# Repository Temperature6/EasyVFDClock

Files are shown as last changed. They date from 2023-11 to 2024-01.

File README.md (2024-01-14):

# STM32 - VFD Clock

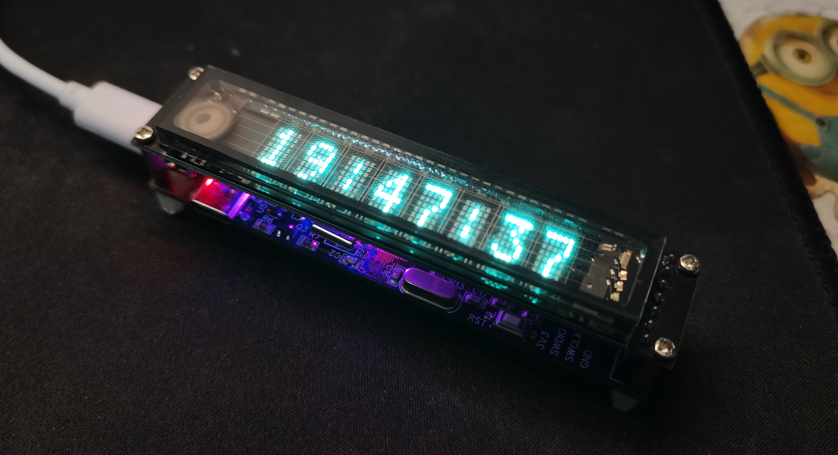
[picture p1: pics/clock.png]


### 简介

基于STM32F103C8T6的时钟，屏幕是VFD屏幕（Vaccum Fluorescent Display，真空荧光显示屏）

**功能**：时间显示，日期显示，开机显示字符串，可控的三个彩色LED（V1版本目前除了可控的常亮常灭没有其他功能），按键校时，上位机校时，设置亮屏时间，支持一键烧录

**上位机功能**：校时，设置日期显示格式，设置开机字符串，屏幕保护设置，LED设置，亮度设置（Python版的上位机提供了命令行批量操作，Qt版没有）

### 说明

#### **1.时钟电路**

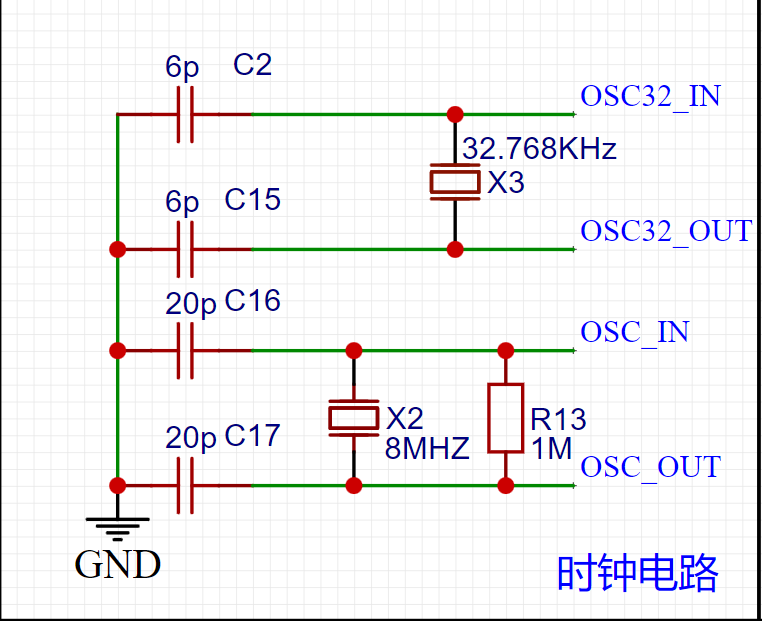
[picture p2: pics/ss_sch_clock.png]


32.768KHz晶振的起振电容（C2，C15）最好选择6pF，或者不贴

我选的低速晶振是是±5ppm的高精度晶振，实测在24℃的室内大概每天快4秒，如果能买到更高精度的晶振也可以用

#### **2.串口电路**

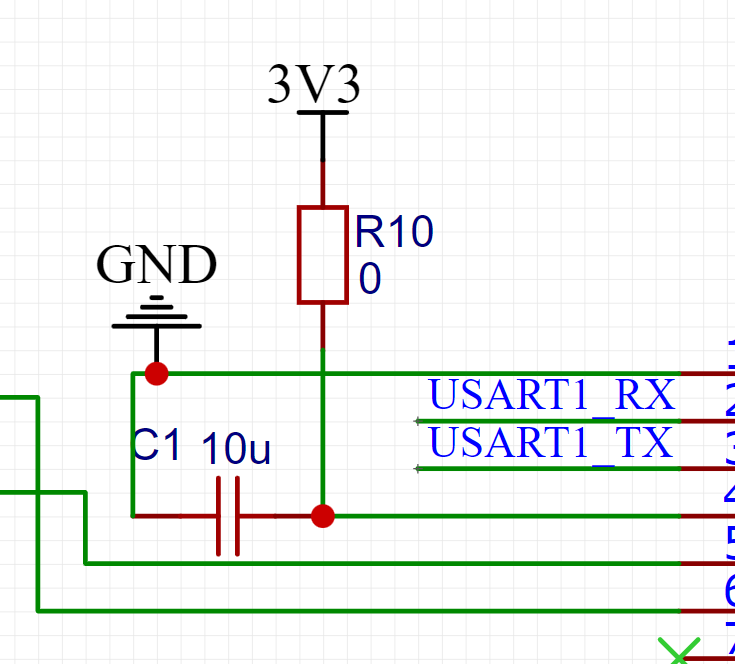
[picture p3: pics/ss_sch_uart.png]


C1是ch340c的去耦电容，贴0.1uF或者10uF，R10可以不贴

#### 3.测试点

背后有多个测试点

**B1_0：** STM32单片机BOOT1拉低（**需要连接**）

**B0_0：** STM32单片机BOOT0拉低（不需要连接，串口烧录电路自带下拉，但是连接也没什么影响，可以删去）

**B1_1：** STM32单片机BOOT1拉高（不需要连接，可以删去）

**B0_1：** STM32单片机BOOT0拉高（不需要连接，可以删去）

**WP_TO_GND：** EEPROM的WP引脚拉低，拉高之后AT24C02进入写保护模式，这里的设计实际上有问题，测试点另一边应该连接VCC，（写保护模式启用后，数据只能读出不能写入，一般不需要连接，可以删去）

**EN_A1：** VFD屏幕的EN引脚是否连接到单片机的PA1引脚（**需要连接**）

**EN_5V：** VFD屏幕的EN引脚是否连接到5V引脚，这样屏幕不受单片机控制了（不需要连接，可以删去）

大部分不需要连接的测试点都可以删去，设计的时候是为了防止再版多弄了几个

#### **4.安装**

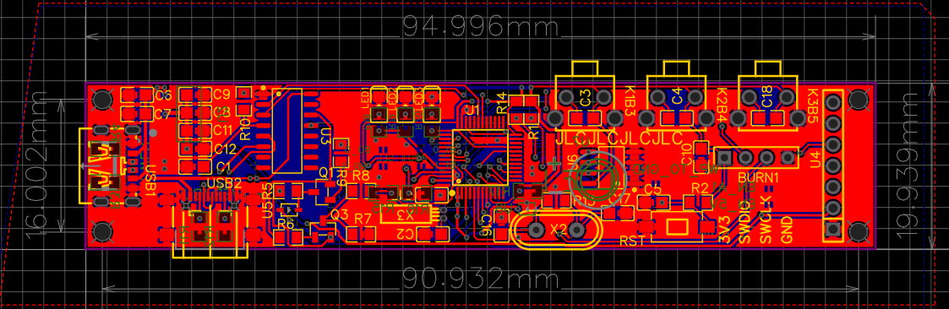
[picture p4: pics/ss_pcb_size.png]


安装孔直径 2.1mm，使用M2的螺丝和铜柱即可，高度建议选择11mm

PCB打样时厚度建议选择1mm

注意这是为VFD屏幕量身定做的底板，我用的VFD屏幕是淘宝店铺  “实用芯片模块”  家的  “8-MD-06INKM模块FUTABA点阵C51显示STM32模组VFD荧光屏8MD06INKM” ，尽量买这个，别的不敢保证尺寸和引脚定义一样

### 上位机

上位机提供了Qt版的图形化界面和Python版的控制台程序，两个版本的上位机都提供源代码

**Qt版：**

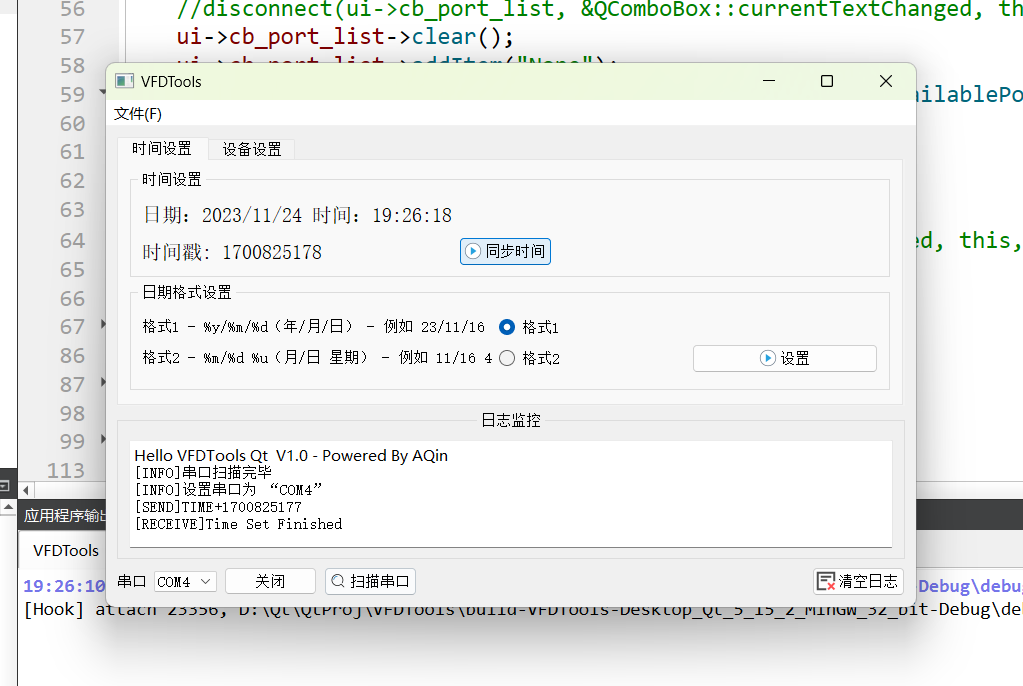
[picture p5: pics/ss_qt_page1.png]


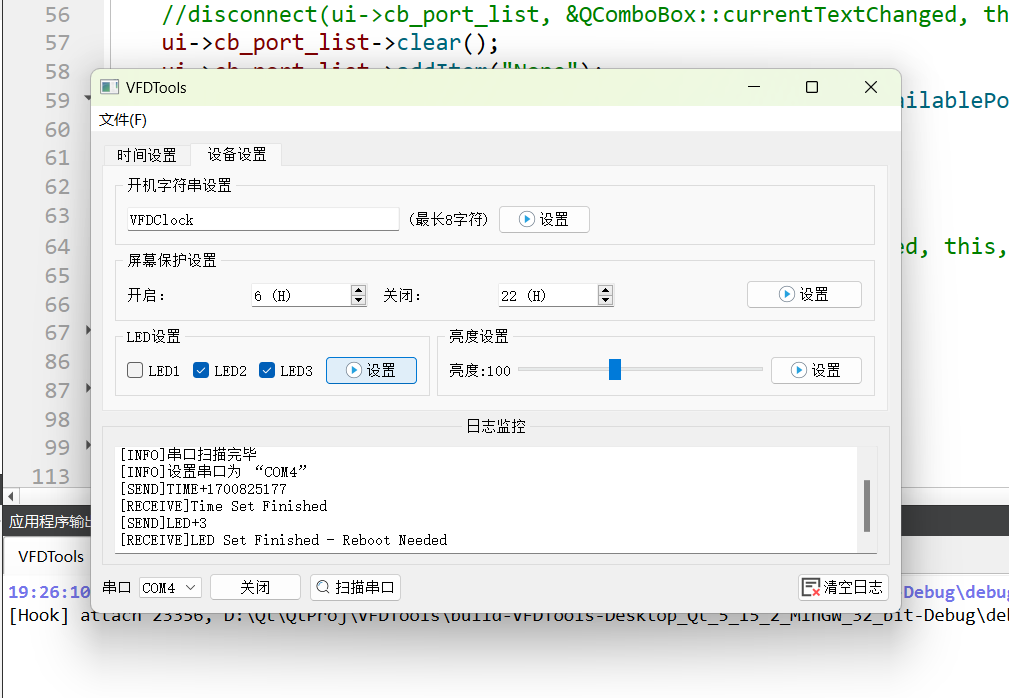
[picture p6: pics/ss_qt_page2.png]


Qt版的编译好的可执行文件在可以在仓库的Release里面下载

上位机和VFD时钟使用串口通信，时钟上提供了两个USB-Type-C接口，下面的可以与电脑通信，需要安装CH340的驱动，官网链接：

[CH340C驱动程序下载链接]: https://www.wch.cn/products/CH340.html?

程序启动时会扫描串口，如果启动时时钟的通信接口没有插到电脑上，再次扫描串口即可在串口的下拉列表里找到设备对应的串口

具体使用方法不过多赘述

**Python版：**

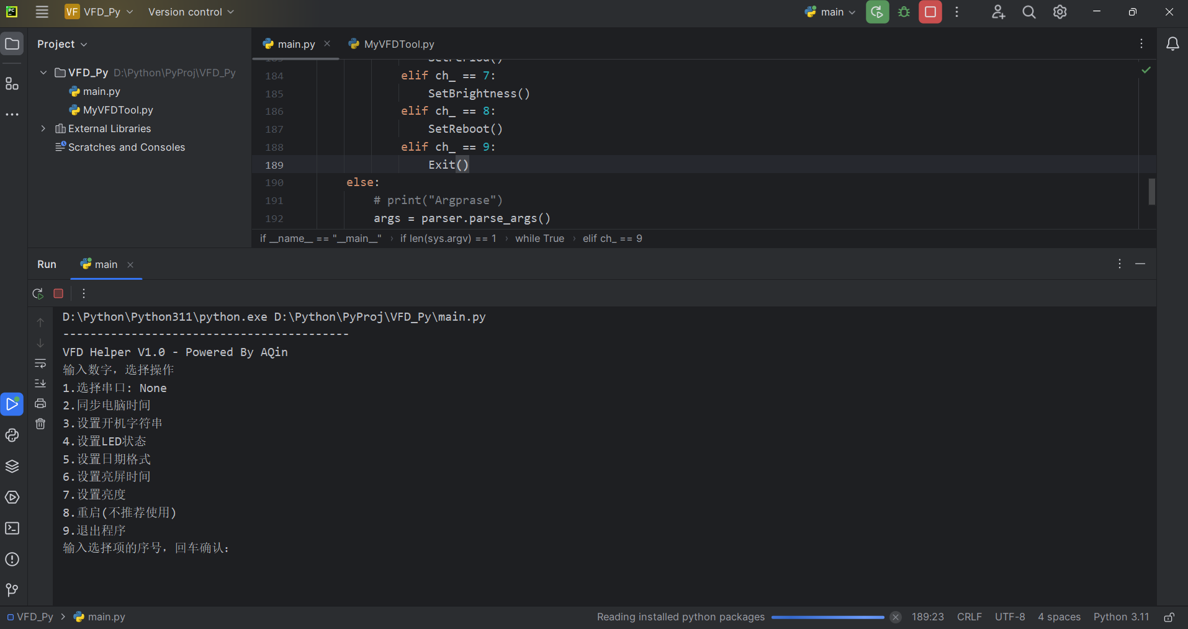
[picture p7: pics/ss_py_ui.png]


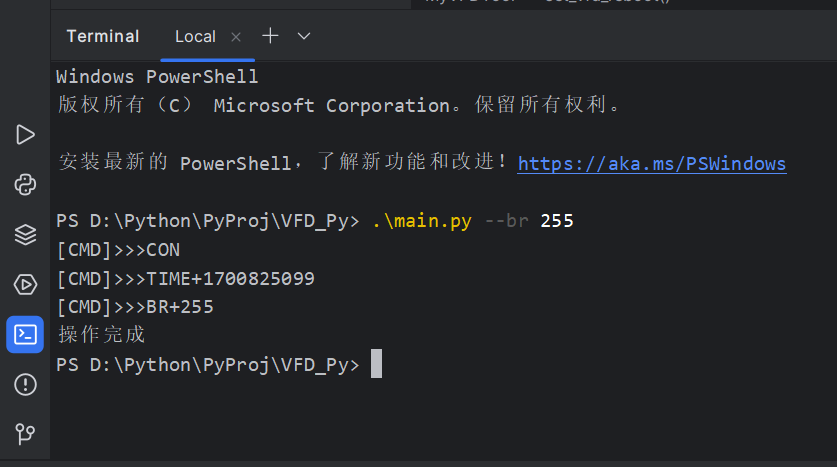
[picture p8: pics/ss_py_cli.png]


python的程序支持控制台直接操作和使用命令行操作，这是为了防止Qt程序无法正常运行的备用方案，需要自己安装解释器（开发时使用的解释器是Python 3.11.4），并安装PySerial库

```
pip install pyserial
```

直接运行main.py即可启动控制台程序，不过多赘述

python程序支持命令行参数，以下是使用例以及参数解释

参数：

```
-p		# 有参数，指定串口设备，如果不指定或者指定为 ‘AUTO’，则自动寻找设备
--st	# 有参数，是否需要同步电脑时间 0 为不需要，1为需要，默认为1
--led	# 有参数，指定三个LED的状态，使用一个整数代替，值的从低位到高位分别代表LED3~LED1的状态，也就是说 7 代表全亮， 0 代表全灭
--dfmt	# 有参数，日期显示格式，1 为 %y/%m/%d， 2 为 %m/%d  %u
--ssd	# 有参数，指定亮屏和息屏时间，使用一个四位整数代替，例如0723表示早上7点亮屏，直到晚上23点息屏。如果需要全天候显示，让这个四位数的前两位数值和后两位数值相等即可，比如0000
--br 	# 有参数，设置亮度，范围是 0 ~ 255，0最暗，255最亮
--str # 有参数，设置开机字符串
```

使用例

```
./main.py --led 5 --dfmt 2 --br 100
```

效果：LED1和LED3亮起，日期格式设置为格式2，亮度设置为100

### 更新日志
#### V1.1 - 2023/12/03
  修复了进入息屏模式之后屏幕仍然会发亮的Bug

  修复发送Reboot命令后彻底死机的Bug
#### V1.2 - 2023/12/05
  增加了新的计时器功能，在时间显示界面按下BTN1后进入计时器模式，按下BTN2开始计时，再次按下BTN2停止计时，暂停状态下按下BTN1会清零并回到主界面，在运行状态下按下BTN1会暂时回到主界面，计时器在后台运行，计时器计时的最大时间是10小时，到达10小时会自动停止

#### V1.3 - 2023/12/10

增加了熄屏状态下强制亮屏的操作，即在熄屏状态下（到达设置的熄屏时间）按下任意按键即可亮屏20秒

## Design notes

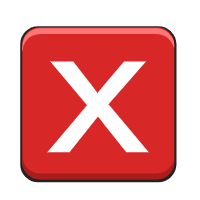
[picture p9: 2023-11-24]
Software/QtVFDTools/VFDTools/VFDTools/pics/exit.png

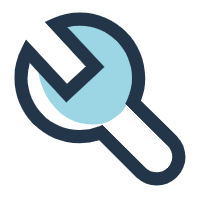
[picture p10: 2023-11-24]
Software/QtVFDTools/VFDTools/VFDTools/pics/tools.png

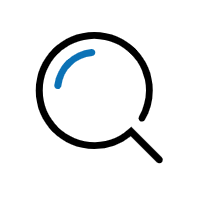
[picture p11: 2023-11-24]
Software/QtVFDTools/VFDTools/VFDTools/pics/scan.png

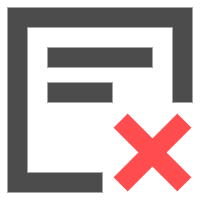
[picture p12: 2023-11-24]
Software/QtVFDTools/VFDTools/VFDTools/pics/clear.png

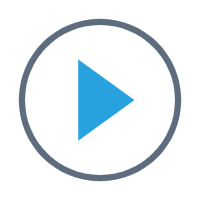
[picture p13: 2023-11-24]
Software/QtVFDTools/VFDTools/VFDTools/pics/set.png

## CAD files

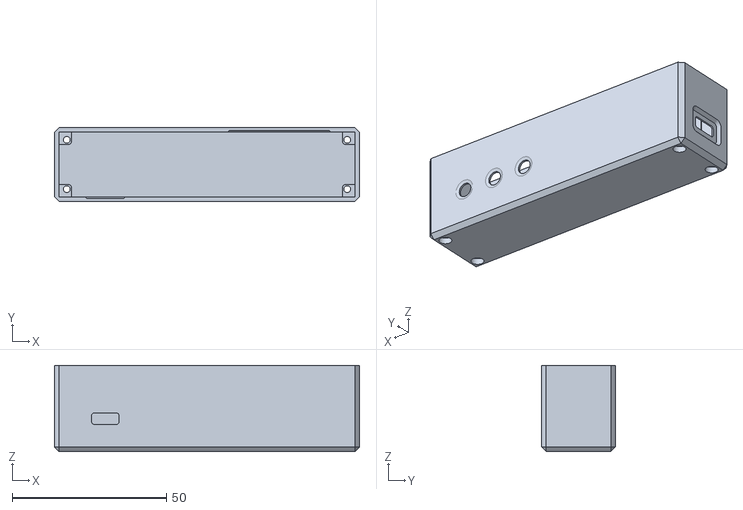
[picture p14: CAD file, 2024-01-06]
3D/vfd外壳 - 双usb.STL
99.0 x 24.0 x 28.0

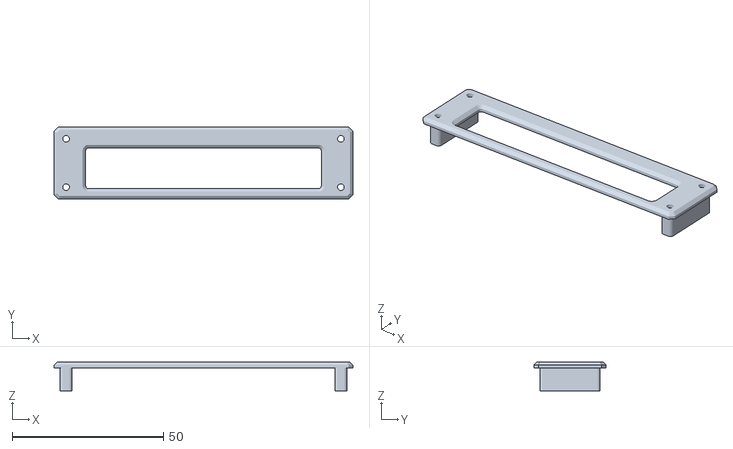
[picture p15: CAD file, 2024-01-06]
3D/vfd前面板.STL
99.0 x 24.0 x 9.50

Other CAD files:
3D/vfd外壳.STL

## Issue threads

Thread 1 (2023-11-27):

你好

liaohuanquan, 2023-11-27:
可以把立创的工程文件也上传一下吗谢谢！，你做的这个项目真的很棒

Temperature6, 2023-11-27:
立创工程在 Hardware/VFD_Clock 下面

liaohuanquan, 2023-11-27:
方便透露一下你购买的元器件大概用了多少钱吗？

Temperature6, 2023-11-27:
最贵的是VFD屏幕，38r，单片机五六块，CH340C一块左右，AT24C02 5毛吧，RTC电池2块，高精度晶振1.5r 5个，电阻电容没法计，50基本上能搞定

liaohuanquan, 2023-11-28:
不打算设计一个外壳吗，我觉得有一个透明外壳很酷

Temperature6, 2023-11-30:
不太会建模（悲）

liaohuanquan, 2023-12-01:
我想添加你的联系方式有一些问题，方便添加一下吗

Closed 2023-11-27.

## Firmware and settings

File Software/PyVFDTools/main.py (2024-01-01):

import sys
import argparse
from MyVFDTool import MyVFDTool
import os
import time

VERSION = 1.0

myVFD = MyVFDTool()
parser = argparse.ArgumentParser(description="Factory Mode")
parser.add_argument("-p",
                    type=str,
                    nargs="+",
                    help="[需要参数]目标设备的串口号，例如 COM1 或者 /dev/ttyUSB1",
                    default="AUTO")
parser.add_argument("--st",
                    nargs="?",
                    help="[需要参数]是否同步时间，值为 0 或 1",
                    default=1)
parser.add_argument("--led",
                    type=int,
                    nargs="+",
                    help="[需要参数]LED状态")
parser.add_argument("--dfmt",
                    type=int,
                    nargs="+",
                    help="[需要参数]日期格式，值为 1 或 2")
parser.add_argument("--ssd",
                    type=int,
                    nargs="+",
                    help="[需要参数]亮屏时间，例如0723")
parser.add_argument("--br",
                    type=int,
                    nargs="+",
                    help="[需要参数]亮度，范围 0 ~ 255")
parser.add_argument("--str",
                    type=str,
                    nargs="+",
                    help="[需要参数]开机字符串")


def AutoSelPort() -> str:
    port_list = myVFD.get_ports()
    for com in port_list:
        myVFD.set_vfd_port(list(com)[0])
        if myVFD.is_opened() and myVFD.vfd_confirm():
            myVFD.close_port()
            port = list(com)[0]
            return port
    return ""


def ClearScreen():
    os.system("cls")


def ShowMenu():
    # ClearScreen()
    print("------------------------------------------")
    print(f"VFD Helper V{VERSION} - Powered By AQin")
    print("输入数字，选择操作")
    print(f"1.选择串口: {myVFD.use_port.name if myVFD.is_opened() else 'None'}")
    print("2.同步电脑时间")
    print("3.设置开机字符串")
    print("4.设置LED状态")
    print("5.设置日期格式")
    print("6.设置亮屏时间")
    print("7.设置亮度")
    print("8.重启(不推荐使用)")
    print("9.退出程序")


def SelectCOM():
    # ClearScreen()
    port_list = myVFD.get_ports()
    print("0 - 自动选择")
    for i in range(len(port_list)):
        print(i + 1, " - ", list(port_list[i])[0], list(port_list[i])[1])
    ch = int(input("输入选择项的序号，回车确认："))

    if ch == 0:
        port = AutoSelPort()
    else:
        port = list(port_list[ch - 1])[0]

    if port == "":
        print("没有找到可用的 VFD Clock 串口设备")
    else:
        myVFD.set_vfd_port(port)


def SyncTime():
    if myVFD.is_opened():
        myVFD.sync_vfd_time()
        print("完成时间同步")
    else:
        print("错误：还没有可用的 VFD Clock 串口设备")


def SetStr():
    if myVFD.is_opened():
        ss = input("输入字符串(使用英文，且长度不大于8个字符)，回车确认:")
        if len(ss) <= 8:
            myVFD.set_vfd_startup_str(ss)
            print("开机字符串设置完成")
        else:
            print("错误：输入的字符串长度大于 8")
    else:
        print("错误：还没有可用的 VFD Clock 串口设备")


def SetLed():
    if myVFD.is_opened():
        print("依次输入三个数字，使用空格隔开，代表LED1，LED2，LED3的状态，1为亮，0为灭")
        in_str = input("输入（例如：1 0 1），回车确认：").split(" ")
        myVFD.set_vfd_led(int(in_str[0]), int(in_str[1]), int(in_str[2]))
        print("LED状态设置完成 - 需要重启")
    else:
        print("错误：还没有可用的 VFD Clock 串口设备")


def SetDateFmt():
    if myVFD.is_opened():
        print("设置日期显示格式:")
        print("1.格式1：%%y/%%m/%%d，例如 23/11/16:")
        print("2.格式2：%%m/%%d  %%u，例如 11/16  4:")
        ch = int(input("输入选择项的序号，回车确认："))
        myVFD.set_vfd_date_fmt(ch)
        print("日期格式设置完毕")
    else:
        print("错误：还没有可用的 VFD Clock 串口设备")


def SetPeriod():
    if myVFD.is_opened():
        print("设置亮屏时间：输入两个数，使用空格隔开\n"
              "分别代表显示屏开启的时间（小时）和显示屏关闭的时间时间（小时）\n"
              "使用24小时制")
        in_str = input("输入数据（例如：7 23），回车确认：").split(" ")
        myVFD.set_vfd_screen_on_period(int(in_str[0]), int(in_str[1]))
        print("亮屏时间设置完毕")

    else:
        print("还没有可用的 VFD Clock 串口设备")


def SetBrightness():
    if myVFD.is_opened():
        print("设置亮度，范围 0 ~ 255：")
        in_str = input("输入数据，回车确认：")
        myVFD.set_vfd_brightness(int(in_str))
        print("亮度设置完毕")

    else:
        print("还没有可用的 VFD Clock 串口设备")


def SetReboot():
    if myVFD.is_opened():
        myVFD.set_vfd_reboot()
        print("已发送重启命令")
    else:
        print("还没有可用的 VFD Clock 串口设备")


def Exit():
    myVFD.close_port()
    sys.exit(0)


if __name__ == "__main__":
    if len(sys.argv) == 1:
        while True:
            ShowMenu()
            ch_ = int(input("输入选择项的序号，回车确认："))
            if ch_ == 1:
                SelectCOM()
            elif ch_ == 2:
                SyncTime()
            elif ch_ == 3:
                SetStr()
            elif ch_ == 4:
                SetLed()
            elif ch_ == 5:
                SetDateFmt()
            elif ch_ == 6:
                SetPeriod()
            elif ch_ == 7:
                SetBrightness()
            elif ch_ == 8:
                SetReboot()
            elif ch_ == 9:
                Exit()
    else:
        # print("Argprase")
        args = parser.parse_args()
        # print(args)
        # 1.设置串口
        if args.p == "AUTO":
            port_name = AutoSelPort()
            if port_name == "":
                print("没有寻找到设备")
                Exit()
        else:
            port_name = args.p[0]
        myVFD.set_vfd_port(port_name)

        # 2.是否需要同步时间？
        if (args.st is not None) and int(args.st):
            print(bool(args.st))
            myVFD.sync_vfd_time()
            time.sleep(0.2)

        # 3.是否需要设置LED
        if args.led is not None:
            val = args.led[0]
            myVFD.set_vfd_led((val >> 2) & 1, (val >> 1) & 1, val & 1)
            time.sleep(0.2)

        # 4.是否需要设置日期格式
        if args.dfmt is not None:
            myVFD.set_vfd_date_fmt(args.dfmt[0])
            time.sleep(0.2)

        # 5.是否需要设置开关屏幕时间
        if args.ssd is not None:
            val = args.ssd[0]
            myVFD.set_vfd_screen_on_period(int(val / 100), val % 100)
            time.sleep(0.2)

        # 6.是否需要设置开关屏幕时间
        if args.br is not None:
            val = args.br[0]
            myVFD.set_vfd_brightness(val)
            time.sleep(0.2)

        # 7.是否需要设置开机字符串
        if args.str is not None:
            val = args.str[0]
            myVFD.set_vfd_startup_str(val)
            time.sleep(0.2)
        print("操作完成")

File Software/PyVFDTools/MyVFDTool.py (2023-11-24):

import serial
import serial.tools.list_ports
import serial.serialutil
import time

VFD_BAUDRATE = 9600
CMD_TIME_FMT = "TIME+{0}\n"     # 时间设置*
CMD_STR_FMT = "STR+{0}\n"       # 设置开机字符串*
CMD_LED_FMT = "LED+{0}\n"       # 设置LED状态*
CMD_DFMT_FMT = "DFMT+{0}\n"     # 设置日期格式*
CMD_SSD_FMT = "SSD+%02d%02d\n"  # 设置亮屏时间*
CMD_REBOOT = "REBOOT\n"         # 重启*
CMD_BR_FMT = "BR+%d\n"          # 设置亮度
CMD_CON = "CON\n"               # 通信确认
CONFIRM_STR = "Hello VFD Clock - Powered By AQin\n"


class MyVFDTool:
    def __init__(self):
        self.use_port = None
        self.use_port_opened = False
        self.portList = list(serial.tools.list_ports.comports())

    def get_ports(self):
        return self.portList

    def set_vfd_port(self, port_name: str):
        try:
            if self.use_port_opened:
                self.use_port.close()
            self.use_port = serial.Serial(port=port_name,
                                          baudrate=VFD_BAUDRATE,
                                          bytesize=serial.EIGHTBITS,
                                          stopbits=serial.STOPBITS_ONE,
                                          timeout=0.5)

        except serial.serialutil.SerialException:
            return False
        self.use_port_opened = self.use_port.isOpen()

    def vfd_send(self, context: str):
        if self.use_port.isOpen():
            self.use_port.write(context.encode('utf-8'))
            print("[CMD]>>>" + context.replace('\n', ''))

    def sync_vfd_time(self):
        self.vfd_send(CMD_TIME_FMT.format(int(time.time())))

    def set_vfd_led(self, led1: int, led2: int, led3: int):
        led_val = led3 | (led2 << 1) | (led1 << 2)
        self.vfd_send(CMD_LED_FMT.format(led_val))

    def set_vfd_startup_str(self, ss: str):
        self.vfd_send(CMD_STR_FMT.format(ss if len(ss) <= 8 else ss[0:8]))

    def set_vfd_date_fmt(self, nfmt: int):
        self.vfd_send(CMD_DFMT_FMT.format(nfmt))

    def set_vfd_screen_on_period(self, beg_hour: int, end_hour: int):
        self.vfd_send(CMD_SSD_FMT % (beg_hour, end_hour))

    def set_vfd_brightness(self, brightness: int):
        self.vfd_send(CMD_BR_FMT % brightness)

    def set_vfd_reboot(self):
        self.vfd_send(CMD_REBOOT)

    def vfd_confirm(self) -> bool:
        self.vfd_send(CMD_CON)
        ret_str = self.use_port.readall().decode('utf-8')

        return ret_str == CONFIRM_STR

    def is_opened(self) -> bool:
        if self.use_port is None:
            return False
        return self.use_port.isOpen()

    def rescan_ports(self):
        self.portList = list(serial.tools.list_ports.comports())

    def close_port(self):
        if self.use_port is not None:
            self.use_port.close()
        self.use_port_opened = False


if __name__ == "__main__":
    myVFD = MyVFDTool()
    myVFD.set_vfd_port("COM6")
    # myVFD.sync_vfd_time()
    # myVFD.set_vfd_led(0, 1, 1)
    # myVFD.set_vfd_startup_str("XinNian")
    # myVFD.set_vfd_screen_on_period(7, 23)
    # print(myVFD.vfd_confirm())

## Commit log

2023-12-03 New Version 1.1
    1.修复了发送REBOOT命令会导致彻底死机的问题
    2.修复了息屏后仍然会以较低亮度运行的问题
2023-12-03 Update main.py
    可以正常使用重启选项了（支持1.1及其以上版本的固件）
2024-01-01 V1.3.2 修复了1.3版本中日期格式1模式下分隔符“/”闪烁的问题
2024-01-06 学长帮忙画的3D外壳
    [vfd前面板.STL, vfd外壳 - 双usb.STL, vfd外壳.STL]
2024-01-06 Update README.md
    更新PCB打样建议
2024-01-06 V1.3.3 - 修复了重新上电会导致时间慢一秒的bug
2024-01-11 V1.4.1 - 增加了动画
